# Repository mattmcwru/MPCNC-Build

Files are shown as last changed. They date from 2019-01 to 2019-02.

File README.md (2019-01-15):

# MPCNC Build

Build info for the [**Mostly Printed CNC**](https://www.v1engineering.com/assembly/).

## Links

* [V1Engineering](https://www.v1engineering.com)
* [Thingiverse](https://www.thingiverse.com/thing:724999)
* [Cut Calculator](https://jscalc.io/calc/Y1Db347ni9eckSKc)

## Parts

* [MPCNC Burly 3/4" EMT (23.5mm OD)](Printed_Parts/MPCNC_BURLY_C_23p5) ([Thingiverse](http://www.thingiverse.com/thing:724999))
* [Harbor Freight Cutout Tool Mount](Printed_Parts/MPCNC_Harbor_Fright_Cutout_Tool_Mount) ([Thingiverse](http://www.thingiverse.com/thing:1645698))

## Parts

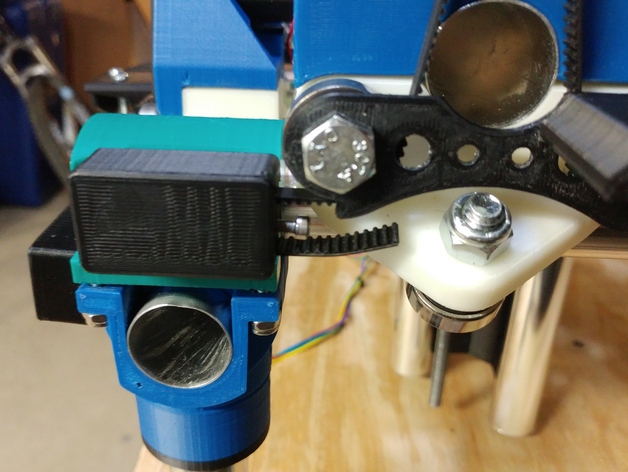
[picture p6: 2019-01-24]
Printed_Parts/MPCNC_Belt_Mount_Tensioner/images/554a77c6b34388b6996187e890862865_preview_featured.jpg

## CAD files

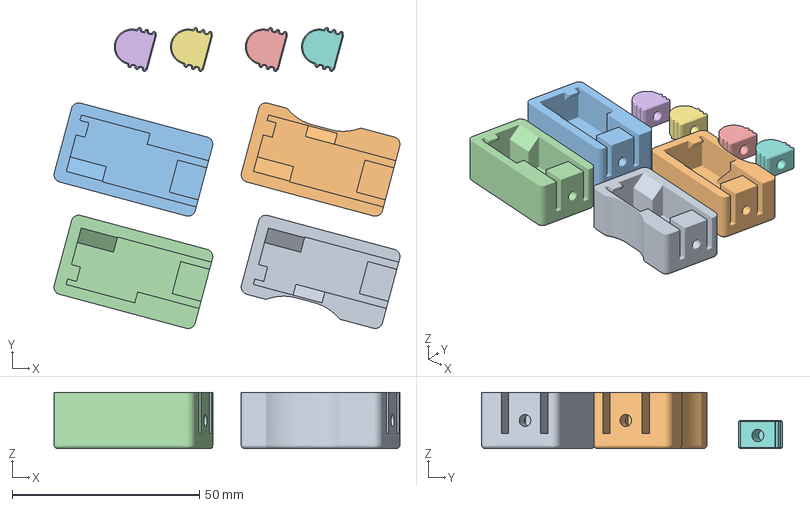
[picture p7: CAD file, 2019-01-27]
Printed_Parts/MPCNC_Belt_Mount_Tensioner/umc_projects/UM2_belt_anchor_fullset.3mf
92.4 x 80.4 x 15.0 mm

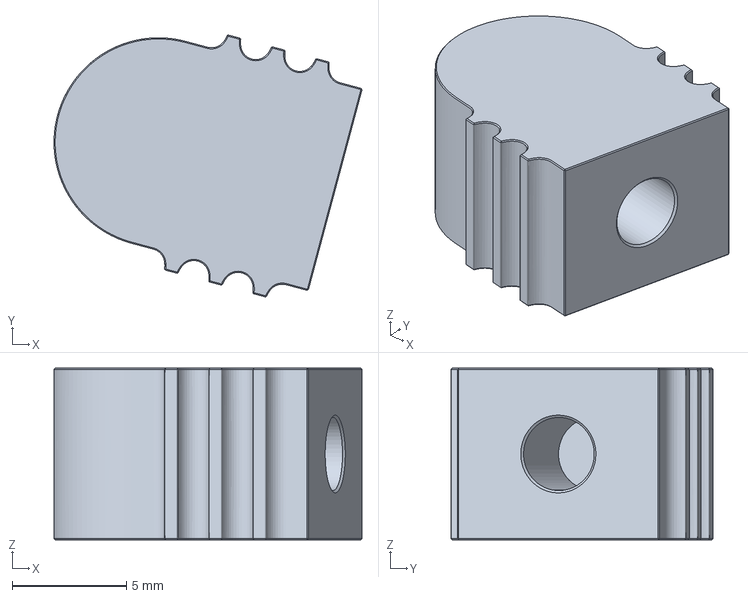
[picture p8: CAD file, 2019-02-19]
Printed_Parts/MPCNC_Belt_Mount_Tensioner/umc_projects/UM2_Belt_Anchor_Block_v2_1block.3mf
13.5 x 11.5 x 7.50 mm

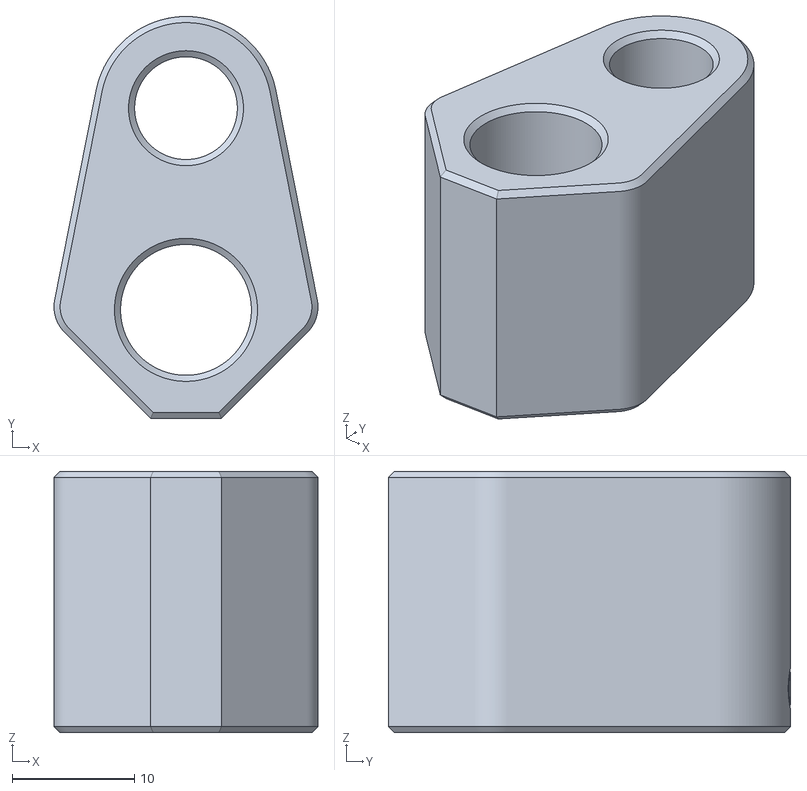
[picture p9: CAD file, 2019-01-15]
Printed_Parts/MPCNC_BURLY_C_23p5/files/Gantry_Spacer_C.STL
21.6 x 32.9 x 21.4

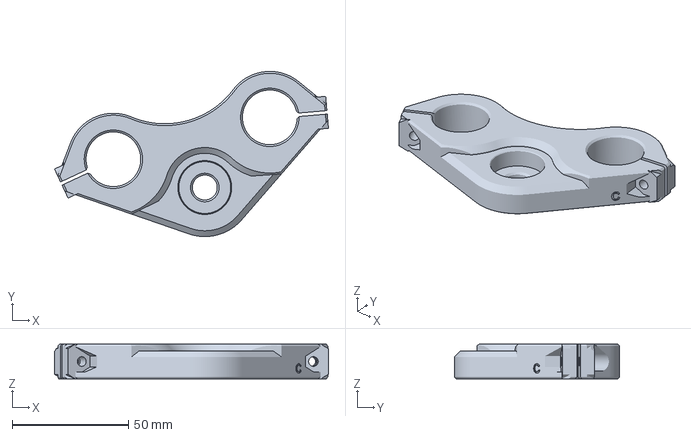
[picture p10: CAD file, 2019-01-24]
Printed_Parts/MPCNC_BURLY_C_23p5/umc-projects/UM2_Z_Lower_C_Burly.3mf
117.8 x 71.0 x 15.0 mm

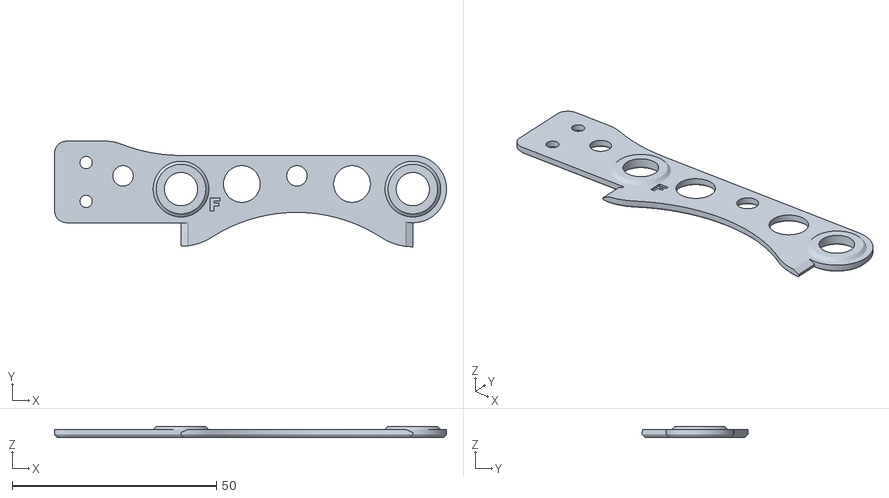
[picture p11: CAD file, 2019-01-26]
Printed_Parts/MPCNC_Dual_Endstop_Plates/files/F_Dual_RollerPlate.STL
96.0 x 25.9 x 2.75

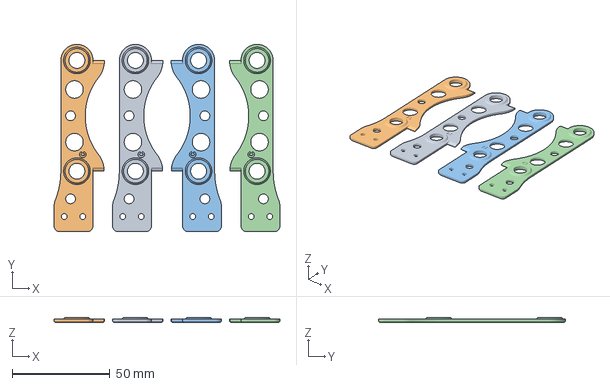
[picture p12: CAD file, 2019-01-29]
Printed_Parts/MPCNC_Dual_Endstop_Plates/umc_projects/UM2_C_Dual_Endstop_RollerPlate.3mf
115.9 x 96.0 x 2.75 mm

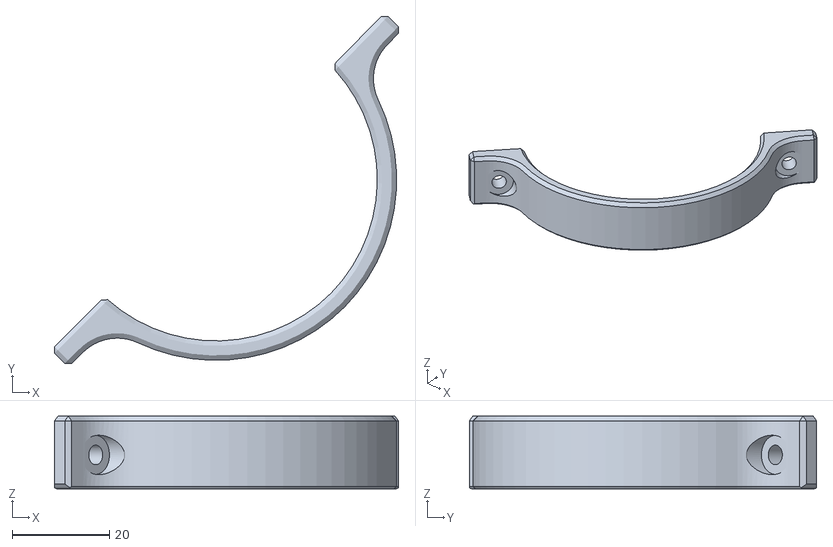
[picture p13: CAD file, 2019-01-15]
Printed_Parts/MPCNC_Harbor_Fright_Cutout_Tool_Mount/files/hf_tool_mount_top_strap.stl
70.8 x 71.5 x 15.0

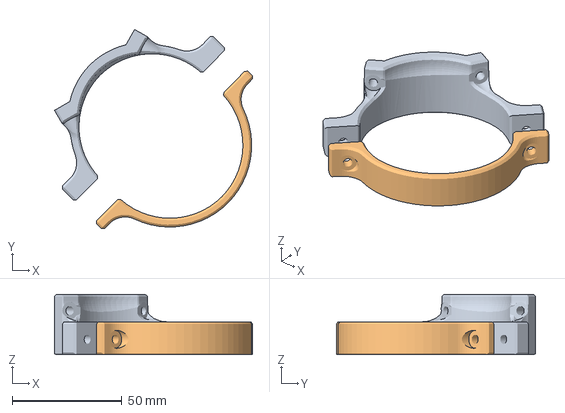
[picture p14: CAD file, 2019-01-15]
Printed_Parts/MPCNC_Harbor_Fright_Cutout_Tool_Mount/umc-projects/UM2_hf_tool_mount_top.3mf
90.0 x 90.5 x 27.5 mm

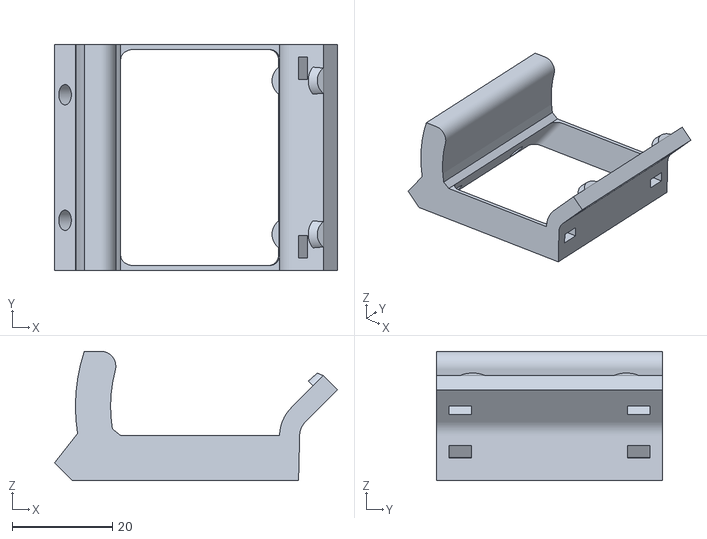
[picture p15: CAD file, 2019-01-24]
Printed_Parts/MPCNC_Pen_Holder/files/pen_holder.STL
56.3 x 45.0 x 25.8

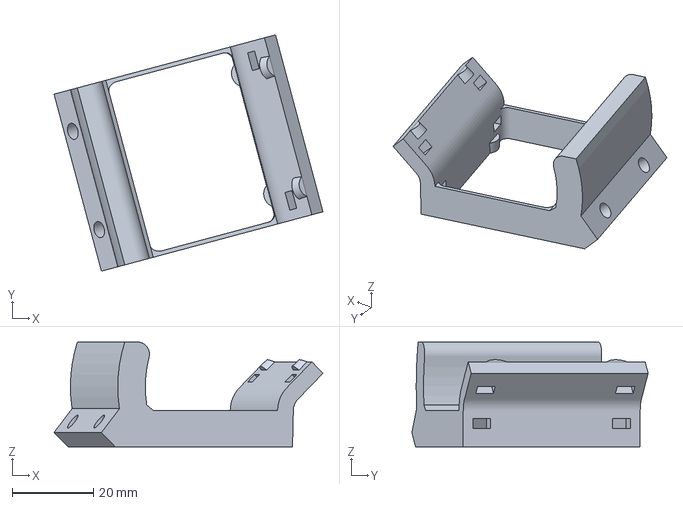
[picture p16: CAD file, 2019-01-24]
Printed_Parts/MPCNC_Pen_Holder/umc_projects/UM2_pen_holder.3mf
66.1 x 58.0 x 25.8 mm

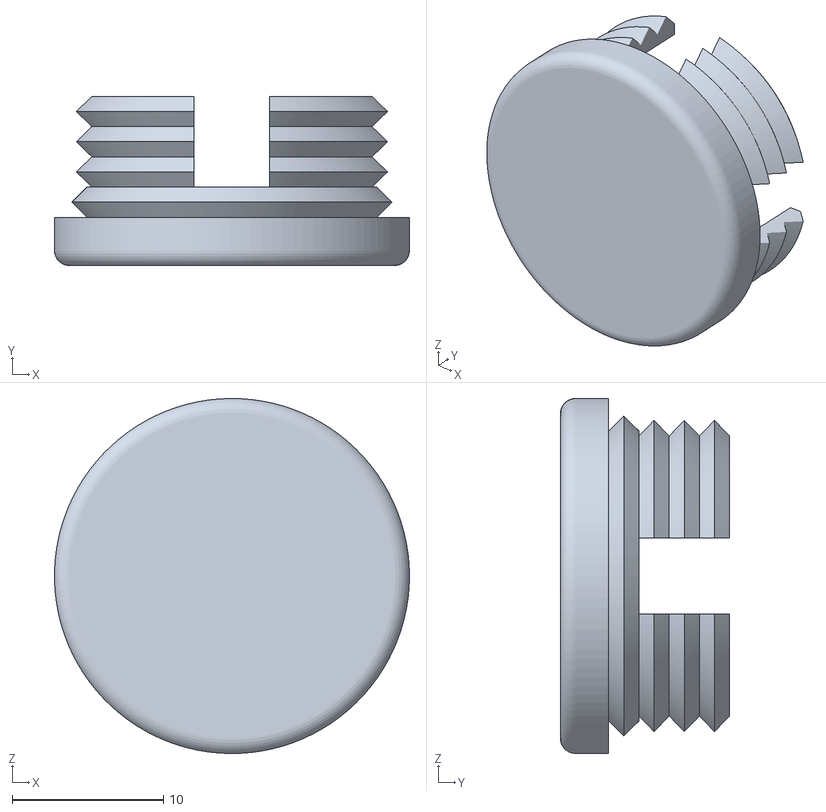
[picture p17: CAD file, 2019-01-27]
Printed_Parts/MPCNC_Pipe_Caps/files/Cap_Closed.stl
23.5 x 11.2 x 23.5

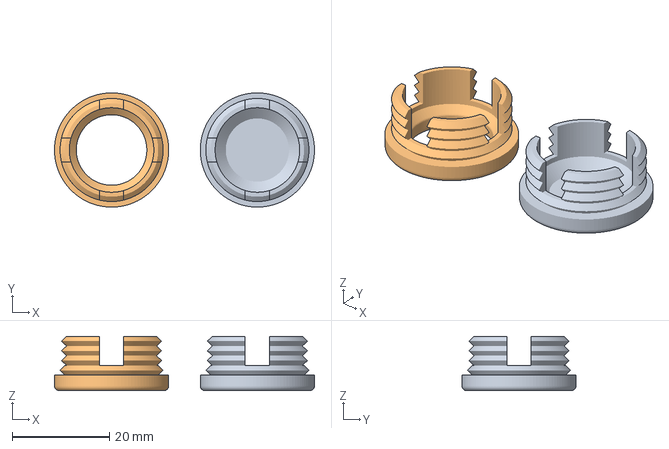
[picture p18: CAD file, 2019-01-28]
Printed_Parts/MPCNC_Pipe_Caps/gcode/UM2_Caps_1each_thinner.3mf
53.5 x 23.5 x 11.2 mm

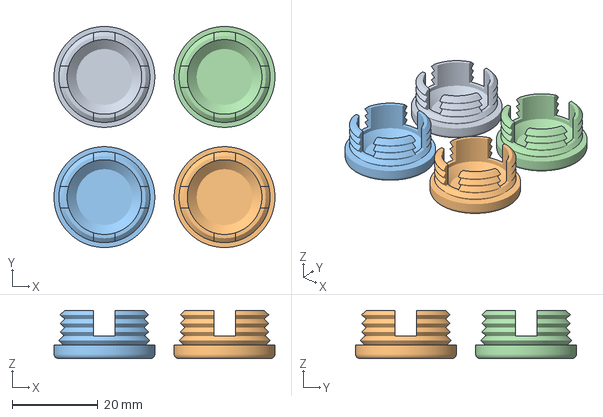
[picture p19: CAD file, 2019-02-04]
Printed_Parts/MPCNC_Pipe_Caps/umc_projects/UM2_Caps_4closed.3mf
51.5 x 51.5 x 11.2 mm

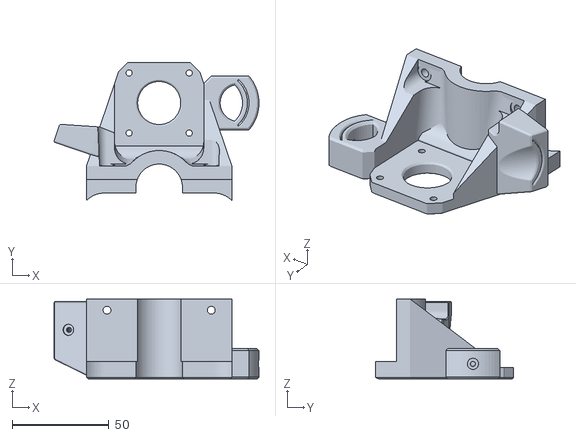
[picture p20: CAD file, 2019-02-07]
Printed_Parts/MPCNC_TapeWireGuide/files/TapeWireGuideZMount_v3.stl
105.8 x 71.4 x 41.2

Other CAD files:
Printed_Parts/MPCNC_TapeWireGuide/umc_projects/UM2_TapeWireGuideZMount_v3.3mf
Printed_Parts/MPCNC_Belt_Mount_Tensioner/files/Belt_Anchor_Block_v2.1.stl
Printed_Parts/MPCNC_Belt_Mount_Tensioner/umc_projects/UM2_Belt_Anchor_Block_v2.1.3mf
Printed_Parts/MPCNC_BURLY_C_23p5/files/Lock-CornerC.STL
Printed_Parts/MPCNC_BURLY_C_23p5/files/BottomM_CornerC.STL
Printed_Parts/MPCNC_BURLY_C_23p5/files/Bottom_CornerC.STL
Printed_Parts/MPCNC_BURLY_C_23p5/files/C-Foot_2018.STL
Printed_Parts/MPCNC_BURLY_C_23p5/files/C-Roller.STL
Printed_Parts/MPCNC_BURLY_C_23p5/files/C-RollerM.STL
Printed_Parts/MPCNC_BURLY_C_23p5/files/C-RollerMount.STL
Printed_Parts/MPCNC_BURLY_C_23p5/files/C-RollerPlate.STL
Printed_Parts/MPCNC_BURLY_C_23p5/files/LockM_CornerC.STL
Printed_Parts/MPCNC_BURLY_C_23p5/files/Nut_Trap_Burly.STL
Printed_Parts/MPCNC_BURLY_C_23p5/files/Spacer_Corner_C_Burly.STL
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

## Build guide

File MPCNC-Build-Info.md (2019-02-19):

# FHC MPCNC Build

[**Mostly Printed CNC**](https://www.v1engineering.com)

Working Area: 26" x 16" x 4"

[Cut Calculator](https://jscalc.io/calc/Y1Db347ni9eckSKc)

| Feature | Dim |
|:----:|:----:|
| 3x X-axis Conduit Lengths: | 36.4 |
| 3x Y-axis Conduit Lengths: | 26.4 |
| 2x Z-Rail Lengths: | 11.5 |
| 4x Leg Conduit Lengths: | 3.5 |
| 1x Allthread/Leadscrew length (minimum): | 7 |
| Minimum Table Width (X-axis): | 36.65 |
| Minimum Table Depth (Y-axis): | 26.65 |
| 2x - X-axis Belt Length (minimum): | 42 |
| 2x - Y-axis Belt Length (minimum): | 32 |

Cut List ([Calc](http://workshop-buddy.com/cut-optimization-calculator.html))

1. 10' stock: 36.5" / 36.5" / 36.5" / 3.5" / 3.5"
1. 10' stock: 26.5" / 26.5" / 26.5" / 11.5" / 11.5" / 3.5" / 3.5"

## Parts List

* Reference Parts List: [V1 Eng MPCNC](https://www.v1engineering.com/blog/parts/)

### Found Parts

| | Name | Qty | Cost | Links |
|:---:|:-----:|:-----:|:-----:|:-----:|
| ✅ | Rails (3/4" EMT Conduit) | ~18' | $12.40 | $6.20 / 10' @ [HD](https://www.homedepot.com/p/3-4-in-x-10-ft-Electric-Metallic-Tube-EMT-Conduit-853429/100400406) |
| | PLA Filament | ~1.8kg | $30 | $15 @ Microcenter |
| ✅ | Chicago Electric Cut-out Tool | 1 | $23 ($17.25 w/ 25% off) | Harbor Freight |
| ✅ | 8" Zip Ties | >20 | $1 | Harbor Freight |
|  | Wire | | | |

### TBD Parts

| | Name | Qty | Cost | Links |
|:---:|:-----:|:-----:|:-----:|:-----:|
|  | [Archim2](https://ultimachine.com/collections/electronics/products/archim2?variant=13739792466029) | 1 | $150 | [Amazon](https://www.amazon.com/Mini-RAMBo-3D-Printer-Controller/dp/B00XM7O0TK) |
|  | Mini-Rambo | 1 | $85 | [V1Eng Shop](https://shop.v1engineering.com/products/mini-rambo-1-3)
| ✅ | Rambo 1.4 | 1 | $137 | [V1Eng Shop](https://shop.v1engineering.com/collections/parts/products/rambo-v1-3l) |
|  | 12v ≥5A power supply | 1 |  | 12V/10A $16.99 [Amazon](https://www.amazon.com/LEDMO-Switching-Converter-Adapter-Transformer/dp/B01E6RMASC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) |
| ✅ | GT2 belt (4M = 24″x24″) | ~4m | $8.95 | [Amazon](https://www.amazon.com/Meters-pitch-wide-Timing-printer/dp/B00F2IQNX8) (Do not get the steel re-enforced ones.) |
| ✅ | GT2 16T Pulley | 4 | $8.99 | [Amazon](https://www.amazon.com/Qunqi-5packs-Aluminum-Timing-Printer/dp/B01IMPM44O) |
| ✅ | 608 2-RS Bearings | 53 | $34.42 | $12.99 / 20 [Amazon](https://www.amazon.com/Pack-608-2RS-Ball-Bearing-Skateboards/dp/B07C6FL8TW) |
| ✅ | Nema 17 Steppers | 5 | $65 | [Amazon](https://www.amazon.com/Stepper-Motor-Bipolar-4-lead-Printer/dp/B00QEYADRQ) |
|  | Wiring harness |  |  |  |
|  | Plywood Base Sheet? |  |  |  |
|  | Dust Collection |  |  |  |
| ✅ | Tape Measure Strips | 3 | $0 | [Used](https://www.v1engineering.com/forum/topic/better-than-a-cable-chain/#post-49738) for wire guides in wire sleeve |
| ✅ | Wire Sleeve | 15' | $1.80 | $11.98 / 100' [Amazon](https://www.amazon.com/dp/B07CVG5YST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) |
| ✅ | End Stop Switch | 4 | $2.80 | $6.99 / 10 [Amazon](https://www.amazon.com/URBESTAC-Momentary-Hinge-Roller-Switches/dp/B00MFRMFS6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) |
|  | Emergency Stop Button | 1 | | [V1Shop](https://shop.v1engineering.com/collections/parts/products/emergency-stop-button) / [IDEC](http://us.idec.com/Common/Download.aspx?d=193354) / [Omron](https://industrial.omron.us/en/products/a22e#specifications_ordering_info) |

### Bolts and Hardware

|  | Name | Qty | Cost | Links |
|:-----:|:-----:|:-----:|:-----:|:-----:|
| ✅ | 300mm T8 Leadscrew, nut, and coupler | 1 | $9.86 | [Amazon](https://www.amazon.com/OctagonStar-L300mm-Start-Screw-Printer/dp/B01HBHUSPQ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) |
| ✅ | 5mm to 8mm flexible coupler | 1 | $3.13 | $6.26 / 2 Amazon |
|  | Dry Teflon Lubricant |  | $6.99 | [Amazon](https://www.amazon.com/dp/B003UTX0R8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) |
|  | Lithium Grease on Leadscrew (bad?) | | $12.88 | [Amazon](https://www.amazon.com/DuPont-Teflon-Lithium-Grease-Aerosol/dp/B000GKTZIW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) |
| ✅ | 5/16-18 X 5 | 1 | $2.06 | $12.40 / 10 [Grainger](https://www.grainger.com/product/FABORY-5-16-18-3AVC7) $2.06 Fastenal |
| ✅ | 5/16-18 X 2.5 | 12 | $6.24 | $13.00 / 25 [Grainger](https://www.grainger.com/product/FABORY-5-16-18-41UG74) |
| ✅ | 5/16-18 X 1.5 | 2 | $1.32 | $14.25 / 50 [Grainger](https://www.grainger.com/product/FABORY-5-16-18-41UG70)  $0.6578 / 1 [Fastenal](https://www.fastenal.com/products/details/70059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)|
| ✅ | 5/16-18 X 1.25 | 28 | $7.78 | $13.35 / 50 [Grainger](https://www.grainger.com/product/FABORY-5-16-18-41UG69) |
|  |  |  |  | Aluminum? for moving parts (>$$$) |
| ✅ | 5/16-18 Nylock Nuts | 43 | $7.87 | $9.15 / 50 [Grainger](https://www.grainger.com/product/FABORY-5-16-18-Nylon-Insert-Lock-22RV97) |
| ✅ | M3-0.5 X 10 | 19 | $1.02 | $0.0511 / 1 [Fastenal](https://www.fastenal.com/products/details/QM2510010A20000) |
| ✅ | #6-32 X.75 | 57 | $7.81 | HEX CAP $13.70 / 100 [Grainger](https://www.grainger.com/product/FABORY-6-32-x-3-4-6XA61) |
|  |  |  | $0.30 | Machine Screw **DEAL** $0.52 / 100 [Grainger](https://www.grainger.com/product/GRAINGER-APPROVED-6-32-Machine-Screw-2EE88) |
| ✅ | #6-32 Nylock nuts | 57 | $3.60 | $3.15 / 50 [Grainger](https://www.grainger.com/product/FABORY-6-32-Nylon-Insert-Lock-Nut-22RV93) |
|  | M3-0.5 X 20 | 8 |  |  |
|  | M3 Nuts | 8 |  |  |

### Part Orders

#### Fastenal

| Name | Qty | Cost |
|:-----:|:-----:|:-----:|
| 5/16-18 X 5 | 1 | $2.06 |
| 5/16-18 X 1.5 | 2 | $1.32 |
| M3-0.5 X 10 | 20 | $1.02 |
| S&H + Tax |  | $0.77 |
| Total  |  | $5.17 |

#### Grainger

| Name | Qty | Cost |
|:-----:|:-----:|:-----:|
| 5/16-18 X 2.5 | 25 | $13.00  |
| 5/16-18 X 1.25 | 50 | $13.35 |
| 5/16-18 Nylock Nuts | 50 | $9.15 |
| #6-32 X.75 | 100 | $0.52 |
| #6-32 Nylock nuts | 100 | $6.30 |
| S&H + Tax |  | $3.39 |
| Total  |  | $45.71 |

#### Amazon

| Name | Qty | Cost |
|:-----:|:-----:|:-----:|
| 608 2-RS Bearings | 60 | $38.97 |
| 5m GT2 2mm Belt w/ 5 GT2 16T Pulley | 1 | $14.99 |
| Nema 17 Steppers | 5 | $65 |
| PET 1/2" Wire Sleeve | 100' | $11.98 |
| End Stop Switchs | 10 | $6.99 |
| 5mm to 8mm flexible coupler | 2 | $6.26 |
| 200 mm leadscrew | 1 | $5.99 |
| Total  |  | $150.18 |

Total: $201.06

## Printed Parts

23.5mm parts for 3/4" EMT conduit

Cura Settings:

* 1.5mm layer height (0.4mm nozzle)
* Wall Count = 3 (0.4mm wall line width?)
* Infill 40%-55% Tri-hexagon
	* Rotate parts 15° to align infill with shell (???)

| Name | Qty | Color | STL | Gcode | Time | Total Time | Grams | Total Grams |
|:----:|:----:|:----:|:----:|:----:|:----:|:----:|:----:|:----:|
| **FRAME** |
| Bottom Corner | 2 ✅ | BLACK | [Bottom_CornerC.STL](MPCNC_BURLY_C_23p5/files/Bottom_CornerC.STL) | []() | 2:35 | 5:10 | 34.7 | 69.4 |
| Bottom Corner Mirror | 2 ✅ | BLACK | [BottomM\_CornerC.STL](MPCNC_BURLY_C_23p5/files/BottomM_CornerC.STL) | []() | 2:35 | 5:10 | 34.7 | 69.4 |
| Lock Corner | 2 ✅ | BLACK | [Lock-CornerC.STL](MPCNC_BURLY_C_23p5/files/Lock-CornerC.STL) | [UM2\_LockCorners\_1each.gcode](UM2_LockCorners_1each.gcode) (2 up) | 1:49 | 3:38 | 18 | 36 |
| Lock Corner Mirror | 2 ✅ | BLACK | [LockM_CornerC.STL](MPCNC_BURLY_C_23p5/files/LockM_CornerC.STL) | ^^^^ | 1:49 | 3:38 | 18 | 36 |
| Top Corner | 2 ✅ | RED | [](MPCNC_BURLY_C_23p5/files/) | [UM2\_Top\_CornerC\_test.gcode](UM2_Top_CornerC_test.gcode) | 2:30 | | 25 | 66.1 |
| Top Corner Mirror | 2 ✅ | RED | [](MPCNC_BURLY_C_23p5/files/) | []() | 2:06 | 4:12 | 32.9 | 66.1 |
| Spacer Corner (Burly) | 4 ✅ | BLACK | [](MPCNC_BURLY_C_23p5/files/) | []() | 0:15 | 1:05 | 4.17 | 16.6 |
| Foot (2018) | 4 ✅ | RED | [C-Foot\_2018.STL](MPCNC_BURLY_C_23p5/files/C-Foot_2018.STL) | [UM2\_C-Foot_2018.gcode](UM2_C-Foot_2018.gcode) | 3:39 | 14:36 | 38 | 152 |
|  ^^^^ | | | [UM2\_C-Foot\_2018\_x3.gcode](UM2_C-Foot_2018_x3.gcode) (3 up) | | 11:05 | 11:05 | 114 | 114 |
| Corner Anchor Lower | 4 ✅ | BLACK | [UM2\_belt\_anchor\_fullset.gcode](UM2_belt_anchor_fullset.gcode) | | 4:04 |  | 34 | | 
| Corner Anchor Upper | 4  | RED |  |  | 4:04 |  | 34 | | 
| **XY ROLLERS** |
| Roller | 2 ✅ | BLACK | [C-Roller.STL](MPCNC_BURLY_C_23p5/files/C-Roller.STL) | [UM2\_C-Roller.gcode](MPCNC_BURLY_C_23p5/gcode/UM2_C-Roller.gcode) | 7:39 | 15:18 | 82 | 164 |
| Roller Mirror | 2 ✅ | BLACK | [C-RollerM.STL](MPCNC_BURLY_C_23p5/files/C-RollerM.STL) | [UM2_C-RollerM.gcode](MPCNC_BURLY_C_23p5/gcode/UM2_C-RollerM.gcode) | 6:43 | 13:26 | 68 | 136 |
| Roller Plate (optional Dual) (OLD PLATE DON'T USE) | 4 ✅ | RED | [C-RollerPlate.STL](MPCNC_BURLY_C_23p5/files/C-RollerPlate.STL) | [UM2\_C-RollerPlate_x4.gcode](MPCNC_BURLY_C_23p5/gcode/UM2_C-RollerPlate_x4.gcode) (4 up) | 1:10 | 1:10 | 9 | 9 |
| Endstop Roller Plate | 2 ✅ | RED | | UM2\_C\_Dual\_Endstop\_RollerPlate.gcode | 
| Endstop Roller Plate Mirror | 2 | RED | | UM2\_C\_Dual\_Endstop\_RollerPlate.gcode | 
| Endstop Block | 2 ✅ | BLACK | |  | 
| Endstop Block Mirror | 2 ✅ | BLACK | |  | 
| Roller Stepper Mount  | 4 ✅ | RED | [C-RollerMount.STL](MPCNC_BURLY_C_23p5/files/C-RollerMount.STL) | [UM2\_C-RollerMount.gcode](MPCNC_BURLY_C_23p5/gcode/UM2_C-RollerMount.gcode) | 4:02 | 16:08 | 41 | 164 |
| **MIDDLE ASSEMBLY** |
| XY (Burly) | 2 | BLACK | [XY\_C\_Burly.STL](MPCNC_BURLY_C_23p5/files/XY_C_Burly.STL) | [UM2\_XY\_C\_Burly.gcode](MPCNC_BURLY_C_23p5/gcode/UM2_XY_C_Burly.gcode) | 12:24 | 24:48 | 121 | 242 |
| XYZ (Burly) | 2 ✅ | RED | [XYZ\_C\_Burly.STL](MPCNC_BURLY_C_23p5/files/XYZ_C_Burly.STL) | [UM2\_XYZ\_C\_Burly.gcode](MPCNC_BURLY_C_23p5/gcode/UM2_XYZ_C_Burly.gcode) | 6:48 | 13:36 | 66 | 132 |
| Gantry Spacer  | 2 ✅ | BLACK | [Gantry\_Spacer\_C.STL](MPCNC_BURLY_C_23p5/files/Gantry_Spacer_C.STL) | [UM2\_Gantry\_Spacer\_C.gcode](MPCNC_BURLY_C_23p5/gcode/UM2_Gantry_Spacer_C.gcode) (2 up) | 1:32 | 1:32 | 13 | 13 |
| Nut Trap (Burly) | 2 ✅ | BLACK | [Nut\_Trap\_Burly.STL](MPCNC_BURLY_C_23p5/files/Nut_Trap_Burly.STL) | [UM2\_Nut\_Trap\_Burly.gcode](MPCNC_BURLY_C_23p5/gcode/UM2_Nut_Trap_Burly.gcode) (2 up) | 1:47 | 1:47 | 15 | 15 |
| **Z AXIS** |
| Tool Mount (#6-32) | 1 ✅ | RED | [Tool\_Mount\_C\_6-32.STL](MPCNC_BURLY_C_23p5/files/Tool_Mount_C_6-32.STL) | [UM2\_Tool\_Mount\_C\_6-32.gcode](MPCNC_BURLY_C_23p5/gcode/UM2_Tool_Mount_C_6-32.gcode) | 5:14 | 5:14 | 50 | 50 |
| Z Lower (Burly) | 1 | BLACK | [Z\_Lower\_C\_Burly.STL](MPCNC_BURLY_C_23p5/files/Z_Lower_C_Burly.STL) | []() |  |  | | |
| Z Motor (Burly) | 1 ✅ | RED | [Z\_Motor\_C\_Burly.STL](MPCNC_BURLY_C_23p5/files/Z_Motor_C_Burly.STL) | []() |  |  | | |
| Z Lower & Z Motor (Combo Print) |  | | [UM2\_Z\_Lower\_Motor.gcode](MPCNC_BURLY_C_23p5/gcode/UM2_Z_Lower_Motor.gcode) | 7:19 |  | 73 | |
| **TOOL MOUNTS** |
| [HF Cutout Tool Mount](https://www.thingiverse.com/thing:1645698) | 1 ✅ | RED | [hf\_tool\_mount\_top.stl](MPCNC_Harbor_Fright_cutout_tool_mount/files/hf_tool_mount_top.stl) | [UM2\_hf\_tool\_mount\_top.gcode](MPCNC_Harbor_Fright_cutout_tool_mount/gcode/UM2_hf_tool_mount_top.gcode) | 2:34 |  | 24 |  |
|  | 1 ✅ | RED | [hf\_tool\_mount\_top\_strap.stl](MPCNC_Harbor_Fright_cutout_tool_mount/files/hf_tool_mount_top_strap.stl) | ^^^^
|  | 1 | RED | [hf\_tool\_mount\_bottom.stl](MPCNC_Harbor_Fright_cutout_tool_mount/files/hf_tool_mount_bottom.stl) | [UM2\_hf\_tool\_mount\_bottom.gcode](MPCNC_Harbor_Fright_cutout_tool_mount/gcode/UM2_hf_tool_mount_bottom.gcode) | 2:11 | | 20 | |
| Pen Holder | 1 ✅ | RED | | UM2\_pen\_holder.gcode | 1:12 | | 11 | |

* [MPCNC Belt Mount/Tensioner](https://www.thingiverse.com/thing:1833934) Clips on orginal ends
* [Rotary 4th axis for MPCNC](https://www.thingiverse.com/thing:1877336)

## Thien Baffle Notes

* [JPThien](http://www.jpthien.com/smf/index.php)
* Thin baffle seperator better
* Fully closed baffle will be hard to clean out if jammed (shouldn't be a problem with just CNC and normal sawdust (no large chips like from a planer))
	* May want a way to pull out the baffle from the cabinent to check for wear on the sides or if something breaks
* Overfilling waste box will clog baffle
	* Window to see how full box is (w/ LED light strips)
* Round to rectangle transition instead of a circular transition may cause less turbalance??? 
* [ShopVac Info](https://www.shopvac.com/us/en/shop-vac-reg-faqs)

## Print Log

| Date | Part File | Time | Color | Complete |
|:----:|:---:|:----:|:----:|:----:|
| 1/14/2019 | UM2\_C-Foot\_2018.gcode | 3:39 | RED | ✅ |
| 1/14/2019 | UM2\_XYZ\_C\_Burly.gcode | 6:48 | RED | ✅ |
| 1/15/2019 | UM2\_LockCorners\_1each.gcode | 3:38 | RED | ✅ |
| 1/15/2019 | UM2\_C-Foot\_2018\_x3.gcode | 11:05 | RED | ✅ |
| 1/16/2019 | UM2\_Top\_CornerC\_test.gcode | 2:30 | RED | ✅ |
| 1/16/2019 | UM2\_C-RollerPlate\_x4.gcode | 1:10 | RED | ✅ |
| 1/16/2019 | UM2\_Z\_Motor\_XYZ\_C\_Burly.gcode | 10:54 | RED | ✅ |
| 1/17/2019 | UM2\_LockCorners\_1each.gcode | 3:38 | BLACK | ✅ |
| 1/17/2019 | UM2\_Top\_CornerC\_test.gcode | 2:30 | RED | ✅ |
| 1/17/2019 | UM2\_Bottom\_Corners\_x4.gcode | 11:58 | BLACK | ✅ |
| 1/17/2019 | UM2\_C-RollerMount\_x2.gcode | 8:53 | RED | ✅ |
| 1/18/2019 | UM2\_Gantry\_Corner\_Spacers.gcode | 3:08 | BLACK | ✅ |
| 1/18/2019 | UM2\_TopM\_CornerC.gcode | 2:30 | RED | ✅ |
| 1/22/2019 | UM2\_LockCorners\_1each.gcode | 3:38 | BLACK | ✅ |
| 1/22/2019 | UM2\_TopM\_CornerC.gcode | 2:30 | RED | ✅ |
| 1/22/2019 | UM2\_C-RollerMount\_x2.gcode | 8:53 | RED | ✅ |
| 1/22/2019 | UM2\_C-Roller\_1each.gcode | 14:36 | BLACK | ✅ |
| 1/23/2019 | UM2\_Nut\_Trap\_Burly\_Anchor\_Clips.gcode | 2:15 | BLACK | ✅ |
| 1/23/2019 | UM2\_hf\_tool\_mount\_top.gcode | 2:34 | RED | ✅ |
| 1/23/2019 | UM2\_C-Roller\_1each.gcode | 14:36 | BLACK | ✅ |
| 1/23/2019 | UM2\_Tool\_Mount\_C\_6-32.gcode | 5:14 | RED | ✅ |
| 1/24/2019 | UM2\_pen\_holder.gcode | 1:12 | RED | ✅ |
| 1/24/2019 | UM2\_belt\_anchor\_2each.gcode | 3:38 | BLACK | ✅ |
| 1/24/2019 | UM2\_Z\_Lower\_C\_Burly.gcode | 3:29 | RED | ✅ |
| 1/24/2019 | UM2\_XY\_C\_Burly.gcode | 14:01 | BLACK | ✅ |
| 1/25/2019 | UM2\_hf\_tool\_mount\_bottom.gcode | 2:11 | RED | ✅ |
| 1/25/2019 | UM2\_XY\_C\_Burly.gcode | 14:01 | BLACK | ✅ |
| 1/28/2019 | UM2\_Caps\_1each.gcode | 0:28 | BLACK | ✅ |
| 1/28/2019 | UM2\_C\_Dual\_Endstop\_RollerPlate.gcode | 1:41 | RED | ✅ |
| 1/28/2019 | UM2\_Stop\_Block\_2each.gcode | 0:53 | BLACK | ✅ |
| 1/28/2019 | UM2\_belt\_anchor\_lower\_mirror.gcode | 2:00 | BLACK | ✅ |
| 1/28/2019 | UM2\_belt\_anchor\_upper\_2each.gcode | 4:05 | RED | ✅ |
| 2/3/2019  | UM2\_C\_Dual\_Endstop\_RollerPlateM\_x2.gcode | 0:50 | RED | ✅ |
| 2/3/2019  | UM2\_TapeWireGuideMount\_v8.gcode | 0:40 | BLACK | ✅ |
| 2/3/2019  | UM2\_TapeWireGuideMount\_v8_Mirror.gcode | 0:43 | BLACK | ✅ |
| 2/3/2019  | UM2\_Caps\_4closed.gcode | 0:45 | RED | ✅ |
| 2/3/2019  | UM2\_TapeWireGuideZMount\_v2.gcode | 0:42 | RED | ✅ |
| 2/3/2019  | UM2\_Caps\_6closed\_3open.gcode | 1:53 | BLACK | ✅ |
| 2/3/2019  | UM2\_TapeWireGuideTower\_v2.gcode | 3:33 | RED | ✅ |
| 2/5/2019  | UM2\_TapeWireGuideMount\_v10.gcode | 1:30 | RED | ✅ |
| 2/11/2019 | UM2\_Belt\_Anchor\_Block\_v2.1.gcode | 0:38 | BLACK | ✅ |
| 2/?/2019  | UM2\_TapeWireGuideZMount\_v3.gcode | 5:34 | RED | next |

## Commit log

2019-01-18 Updated print log and files.
    [UM2_Bottom_Corners_x4.3mf, UM2_C-RollerMount_x2.3mf, UM2_C-RollerPlate_x4.3mf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]
2019-01-24 Added more parts.
    [UM2_Nut_Trap_Burly_Anchor_Clips.3mf, UM2_XY_C_Burly.3mf, UM2_belt_anchor_2each.3mf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]
2019-01-24 Updated print log
    [UM2_Z_Lower_C_Burly.3mf]
2019-01-25 Updated print log.
2019-01-26 Added endstop plates.
    [C_Dual_RollerPlate.STL, C_Dual_RollerPlate_M.stl, F_Dual_RollerPlate.STL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]
2019-01-27 Added missing parts.
    [Cap_Closed.stl, Cap_Open.stl, UM2_Caps_1each.3mf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]
2019-01-28 Updated caps.
    [UM2_Caps_1each_thinner.3mf]
2019-01-29 More caps
    [UM2_Caps_4open.3mf, UM2_Caps_6closed_3open.3mf]
2019-01-29 Fixed missing mirrored endstops
    [UM2_C_Dual_Endstop_RollerPlate.3mf, UM2_C_Dual_Endstop_RollerPlateM_x2.3mf]
2019-02-04 Added Tape Wire Guide and switched to closed caps for ends. Updated print log.
    [TapeWireGuideMount_v3.stl, TapeWireGuideMount_v4.stl, TapeWireGuideMount_v5.stl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]
2019-02-05 Lowered angle of tape guide from end mounts.
    [TapeWireGuideMount_v10.stl, UM2_TapeWireGuideMount_v10.3mf]
2019-02-07 Combined tape guides with stepper mount.
    [TapeWireGuideZMount_v3.stl, UM2_TapeWireGuideZMount_v3.3mf]
2019-02-19 Updated anchor blocks for thicker belt.
    [Belt_Anchor_Block_v2.1.stl, Belt_Anchor_Block_v2.stl, UM2_Belt_Anchor_Block_v2.1.3mf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]
